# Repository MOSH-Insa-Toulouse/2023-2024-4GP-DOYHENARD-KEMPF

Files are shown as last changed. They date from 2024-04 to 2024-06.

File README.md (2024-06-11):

# **4A GP - Projet "Du capteur au banc de test" - I4PMH21**

## **Sommaire**
+ [Objectif du projet](https://github.com/MOSH-Insa-Toulouse/2023-2024-4GP-DOYHENARD-KEMPF?tab=readme-ov-file#objectif-du-projet)
+ [Livrables](https://github.com/MOSH-Insa-Toulouse/2023-2024-4GP-DOYHENARD-KEMPF?tab=readme-ov-file#livrables)
+ [LTSpice](https://github.com/MOSH-Insa-Toulouse/2023-2024-4GP-DOYHENARD-KEMPF?tab=readme-ov-file#ltspice)
+ [KiCad](https://github.com/MOSH-Insa-Toulouse/2023-2024-4GP-DOYHENARD-KEMPF?tab=readme-ov-file#kicad)
+ [Shield](https://github.com/MOSH-Insa-Toulouse/2023-2024-4GP-DOYHENARD-KEMPF?tab=readme-ov-file#conception-du-shield)
+ [Code Arduino](https://github.com/MOSH-Insa-Toulouse/2023-2024-4GP-DOYHENARD-KEMPF?tab=readme-ov-file#code-arduino)
+ [Application Android](https://github.com/MOSH-Insa-Toulouse/2023-2024-4GP-DOYHENARD-KEMPF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)
+ [Datasheet](https://github.com/MOSH-Insa-Toulouse/2023-2024-4GP-DOYHENARD-KEMPF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)

## **Objectif du projet**
Dans le cadre d'un cours dispensé lors du 2<sup>nd</sup> semestre de 4<sup>ème</sup> année de Génie Physique à l'INSA de Toulouse, il nous a été proposé de réaliser un capteur low-tech à base de graphite, puis d'en faire une analyse critique argumentée pour en cerner les potentialités mais également pour évoquer des solutions d’amélioration. Ainsi, ce projet nous a permis de balayer l’ensemble du domaine : du capteur jusqu’à la réalisation d’une datasheet et du banc de test.

## **Livrables**
* Un shield PCB branché à une board Arduino UNO sur lequel nous retrouverons différents composants tels que :
  - Un capteur graphite
  - Un circuit d'amplification transimpédence
  - Un module Bluetooth
  - Un encodeur rotatoire
  - Un potentiomètre digital (_qui vient remplacer la résistance R2 du circuit d'amplifiaction_)
  - Un capteur de contrainte commercial

* Une simulation LTSpice du circuit transimpédence

* Un fichier KiCad du shield avec l'ensemble des composants cités en amont

* Un code Arduino qui gère le fonctionnement et les communications des 2 à 6 avec la board

* Un fichier APK Android (_conçue à l'aide du site MIT APP Inventor_) qui permet, à partir d'un smartphone Android, de gèrer l'interface avec le shield Arduino UNO par le biais d'une communication Bluetooth

* La datasheet du capteur graphite

## **LTSpice**
Nous avons réalisé une étude de notre circuit à l'aide du logiciel _LTSpice_. En effet, le capteur étudié ayant une résistance de l'ordre du GOhm, le courant délivré est alors trop faible (de l'ordre du nA). Pour qu'il puisse être exploitable, ce signal en courant doit donc être **filtré** de tout bruit parasite puis **amplifié**. C'est précisément le rôle du montage suivant :

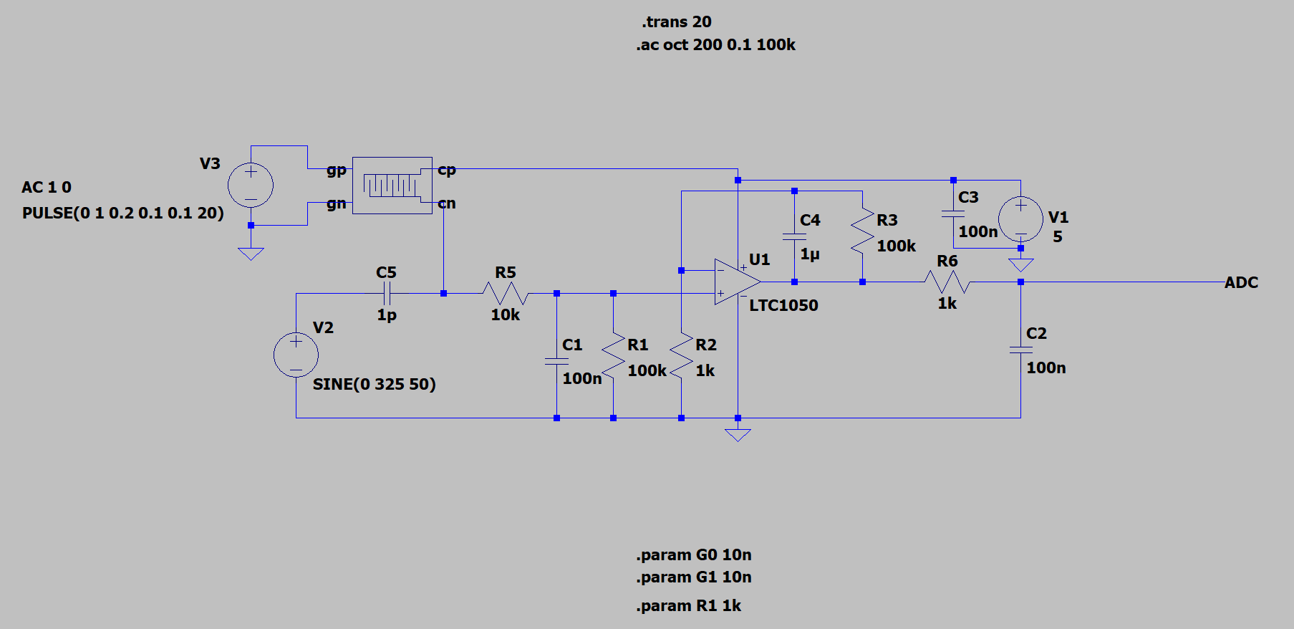
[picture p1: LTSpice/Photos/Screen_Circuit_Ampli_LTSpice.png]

_Circuit d'amplification/atténuation_
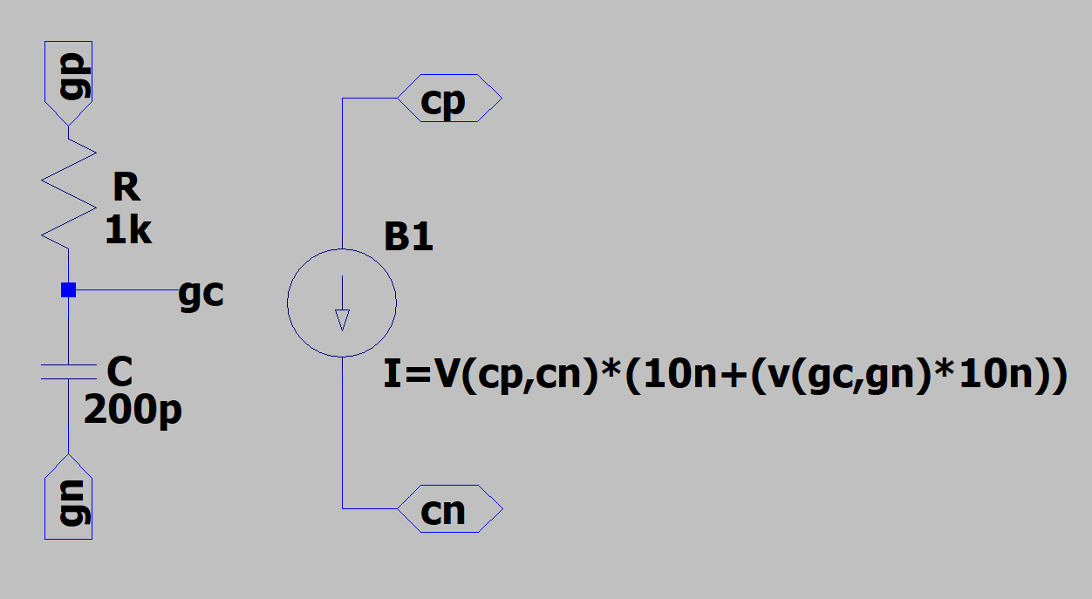
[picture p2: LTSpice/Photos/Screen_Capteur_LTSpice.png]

_Modélisation du capteur_

Ce montage se compose de 3 filtres passe-bas distincts :
- Un 1<sup>er</sup> formé par R<sub>5</sub>, C<sub>1</sub> et R<sub>1</sub>, filtrant les bruits en courant sur le signal d'entrée causés par l’alimentation 5V symbolisé par le 'SINE' + C<sub>3</sub>
- Un 2<sup>nd</sup> formé par C<sub>4</sub> et R<sub>3</sub>, pour réduire la composante de bruit à 50 Hz induite par réseau électrique ambiant
- Un 3<sup>ème</sup> formé par R<sub>6</sub> et C<sub>2</sub>, placé à la sortie de l'amplificateur qui atténue le bruit intrinsèque du circuit

Grâce à ce montage, nous sommes capable de mesurer la résistance du capteur graphite en suivant la formule suivante : $`R_{Meas} = \frac{V_{CC}}{V_{ADC}}*R_1*(1+\frac{R_3}{R_{potentio}})-R_1-R_5`$

Afin de nous assurer que notre circuit jouait bien le rôle de filtreur/amplificateur, nous avons réalisé 2 simulation : une qui vérifiera la correcte amplification du signal en sortie de circuit, l'autre qui permettra de confirmer la bonne atténuation du signal pour des fréquences non souhaitées :

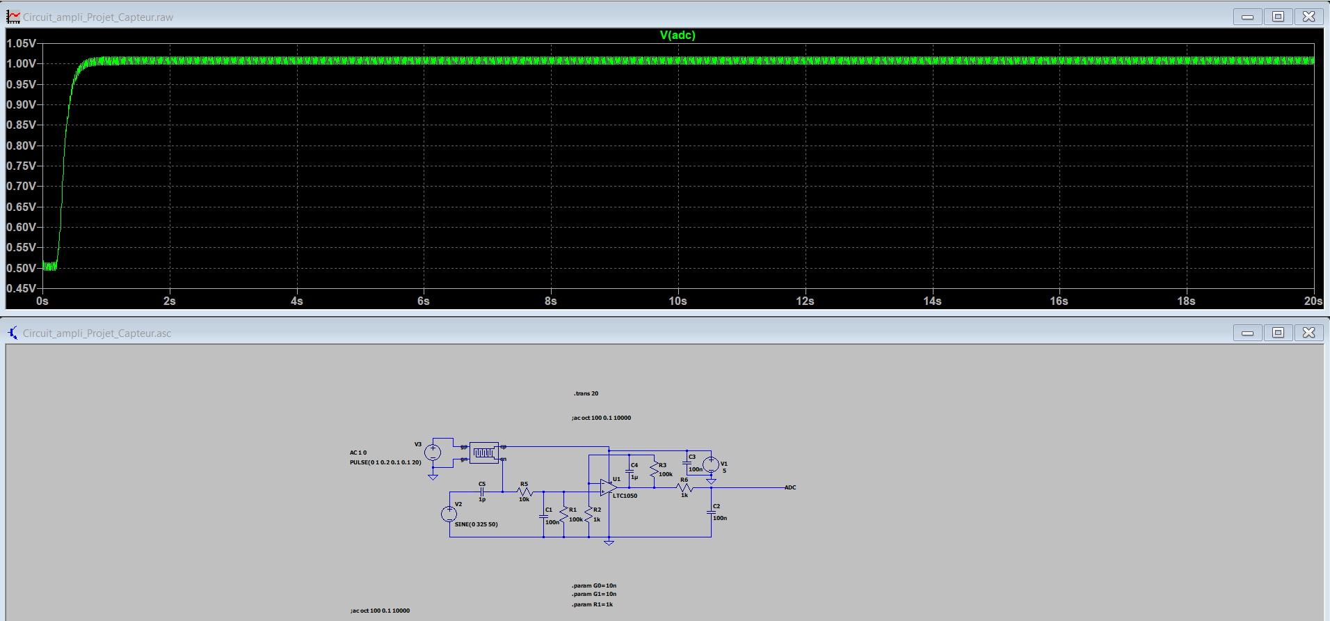
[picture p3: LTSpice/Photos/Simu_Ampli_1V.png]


Nous voyons ici que le signal de sortie est de 1V, soit un ordre de grandeur tout à fait mesurable et donc exploitable dans notre cas.

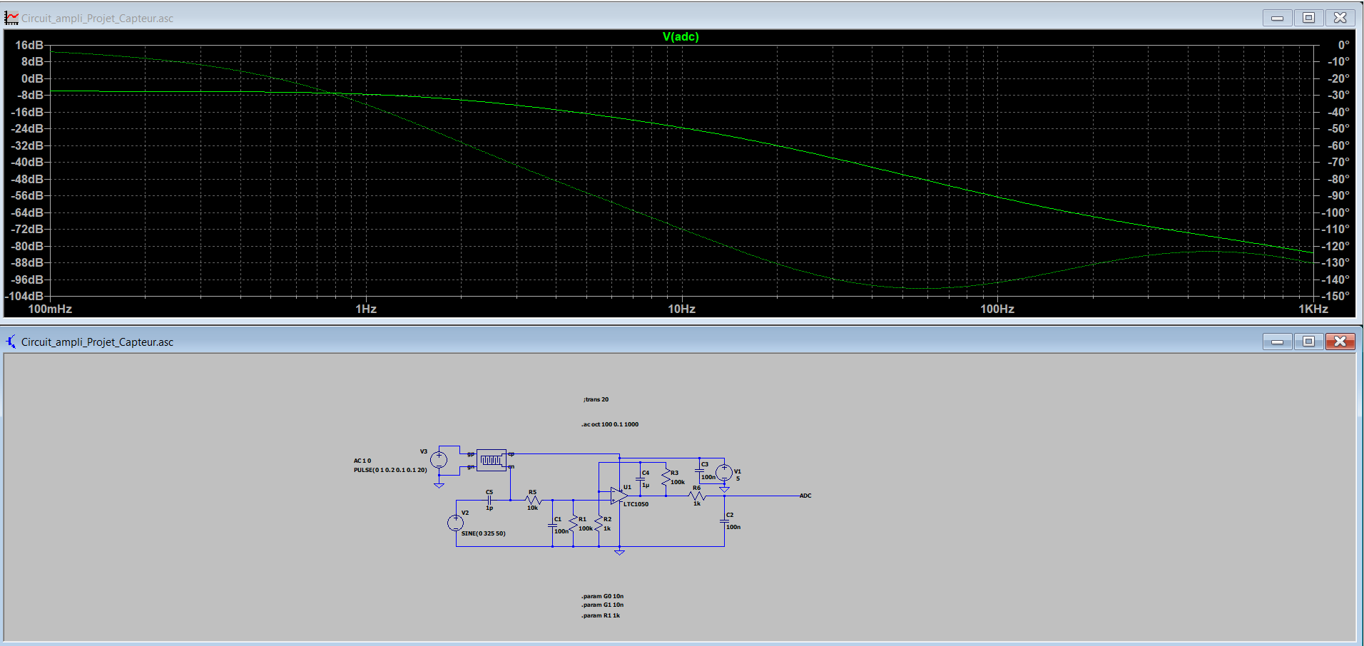
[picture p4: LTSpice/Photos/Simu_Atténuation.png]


Ici, nous avons simulé un courant alternatif grâce auquel il nous sera possible d'observer la réduction du bruit : Nous observons une atténuation d'environ 46 dB à 50 Hz. Le comportement global du circuit est bel est bien passe-bas.

--> La simulation LTSpice est donc conforme aux attentes.

## **KiCad**
Afin de construire un shield PCB qui respecte à la fois les consignes mentionnées dans le document _INSTRUCTIONS for the UF “From the sensor to the test bench” – I4PMH21_ ainsi que les contraintes électroniques, mécaniques et physiques des composants qu'il supportera, il nous a fallu élaborer une maquette virtuelle de ce dernier via le logiciel _KiCad_. Nous avons donc dans un 1<sup>er</sup> temps réalisé une 'schematic' de l'ensemble des composants impliqués :

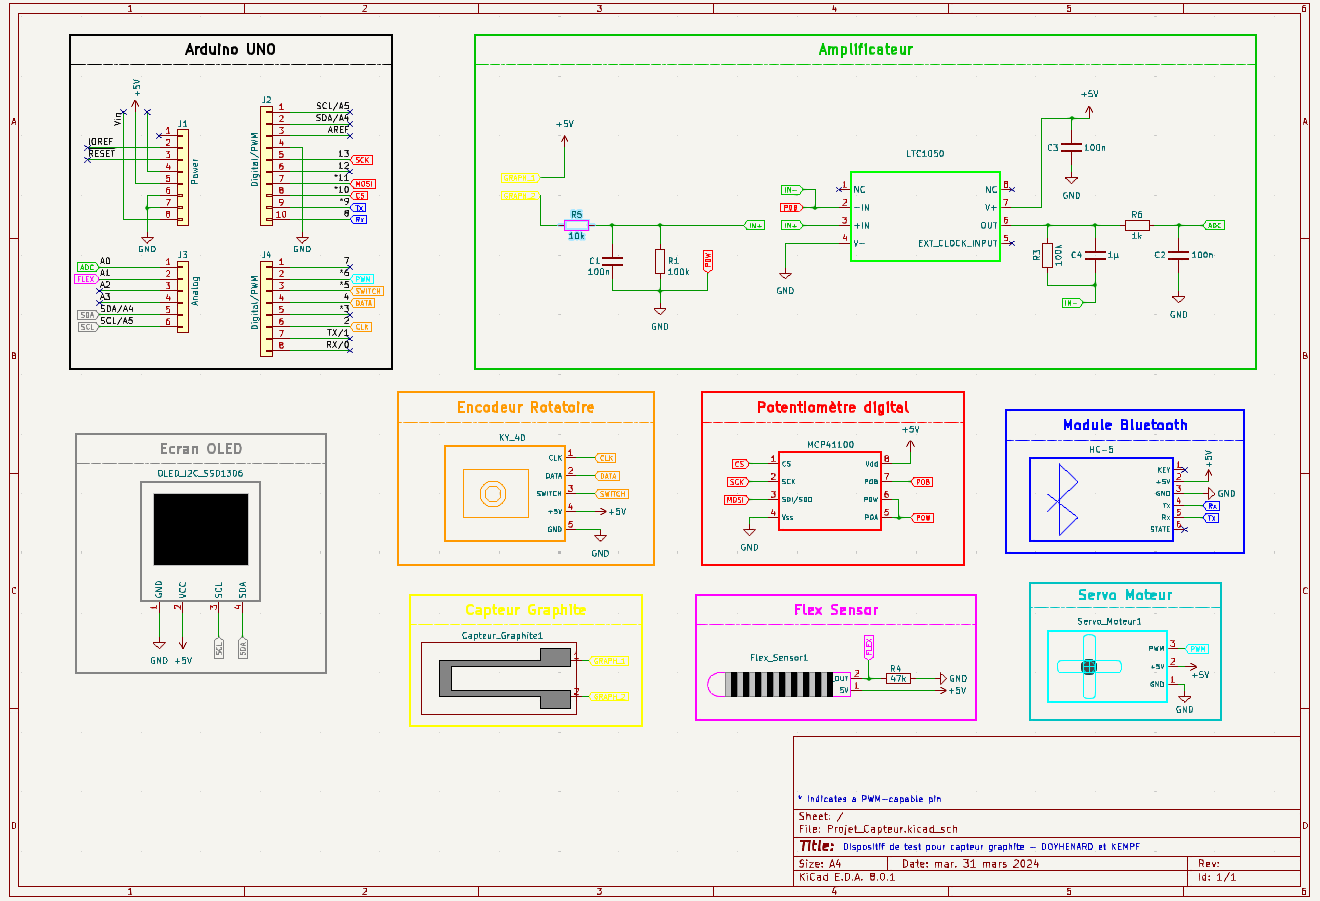
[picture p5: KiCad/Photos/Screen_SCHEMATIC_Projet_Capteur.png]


Nous avons en suite utilisé la partie _PCB_ du logiciel afin de disposer les différents composants sur le shield, en tenant compte de la contrainte liée aux masses, qui doivent être réliées indirectement entre elles via le plan de masse. Nous sommes arrivés au résultat suivant :

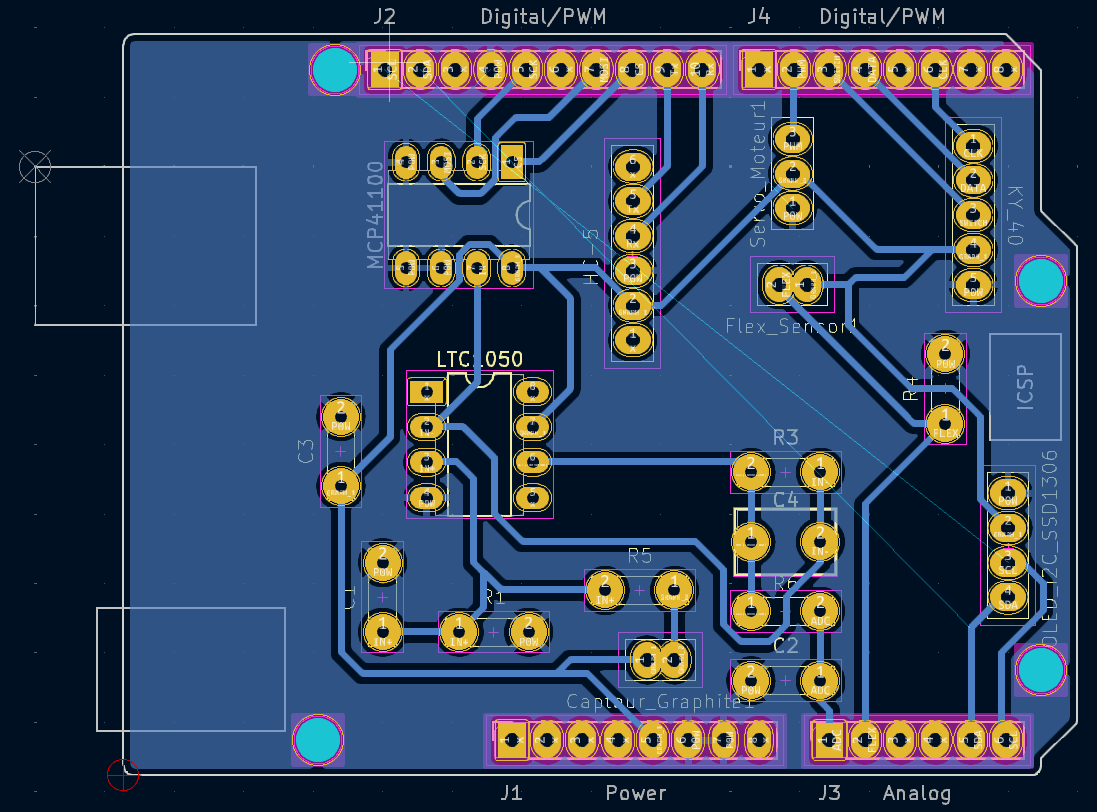
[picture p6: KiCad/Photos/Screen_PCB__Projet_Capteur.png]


Nous avons également effectué un rendu 3D de notre shield afin d'en avoir un 1<sup>er</sup> aperçu 'réaliste', dont voici un cliché pris du dessus :

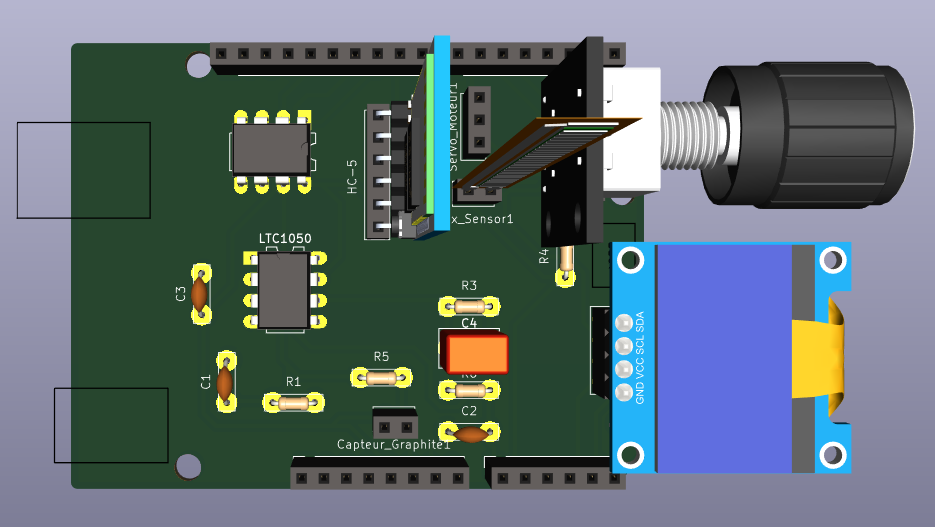
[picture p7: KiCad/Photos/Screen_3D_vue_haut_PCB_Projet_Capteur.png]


## **Conception du shield**
Après validation de notre travail sur _KiCad_ par nos responsables, nous avons procédé à la confection réelle de notre shield, fabriqué à partir d'une plaquette d’époxy recouverte d’une fine couche de cuivre.
Les principales étapes de fabrication sont :
- Une insolation aux UVs de la plaquette grâce au calque modélisé dans la partie PCB de _KiCad_.
- Le retrait de la résine non isolée à l'aide d'un révélateur.
- Le placement de la plaquette dans une solution de percholorure de fer.

A la suite de cela, avons pu assembler les composants sur la plaquette. Pour cela, il a fallu respecter les consignes à appliquer que ce soit au niveau du perçage de la plaquette ou bien du soudage des composants :

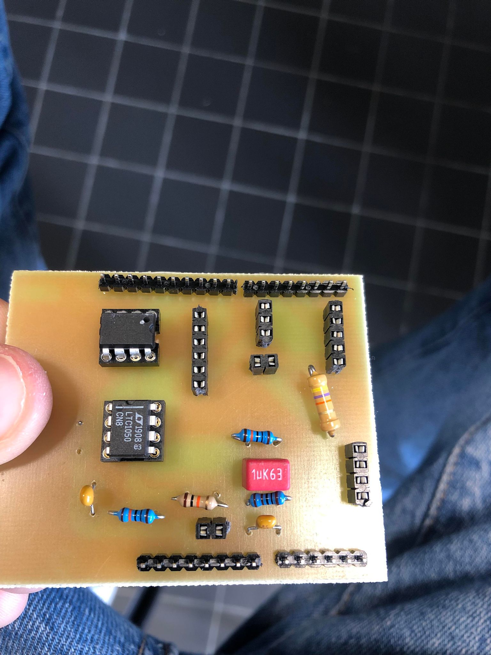
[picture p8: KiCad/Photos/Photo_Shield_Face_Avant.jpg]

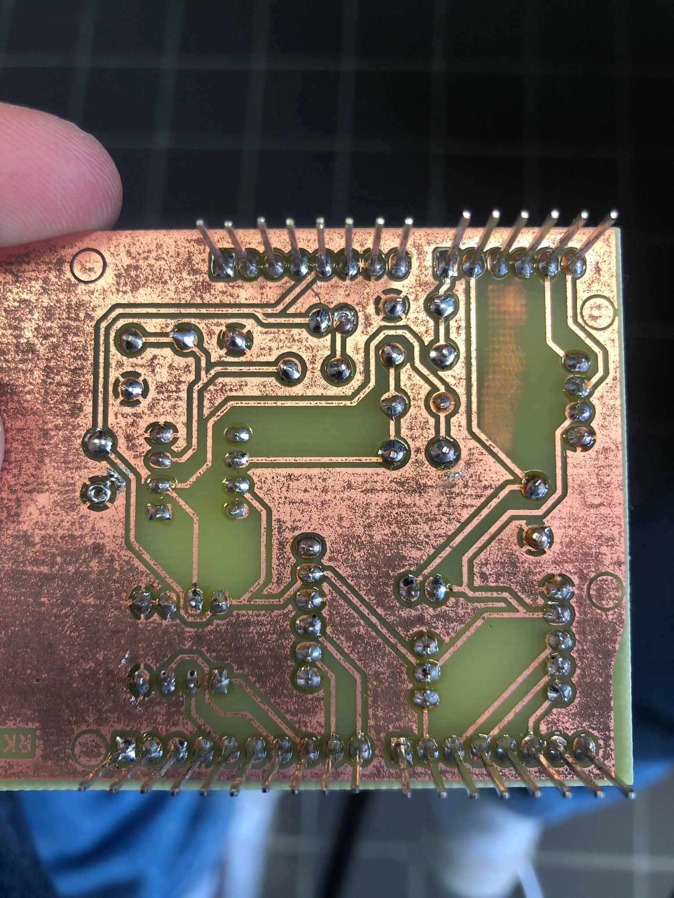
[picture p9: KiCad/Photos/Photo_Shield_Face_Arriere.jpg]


> [!NOTE]
> Nous avons finalement décidé de ne pas nous servir de Servomoteur du fait d'un manque de temps.

## **Code Arduino**
En parallèle de la partie _KiCad_, nous nous sommes attelés à la programmation du **[code Arduino](https://github.com/MOSH-Insa-Toulouse/2023-2024-4GP-DOYHENARD-KEMPF/blob/main/Code%20Arduino/Code_V_Finale.c)** qui permettra la commuication de chacun des composants entre eux mais aussi avec l'Arduino UNO, ainsi qu'avec un smartphone via l'application Android.

## **Application Bluetooth pour Android**
Nous avons réalisé une **[application Android](https://github.com/MOSH-Insa-Toulouse/2023-2024-4GP-DOYHENARD-KEMPF/tree/main/Application%20Android)** à l'aide du site _MIT App Inventor_. Cette application permet de lire les valeurs des capteurs en temps réel, mais aussi de les stocker pour établir des courbes de variation de résistance en fonction de la déformation qui leur est appliquée : 

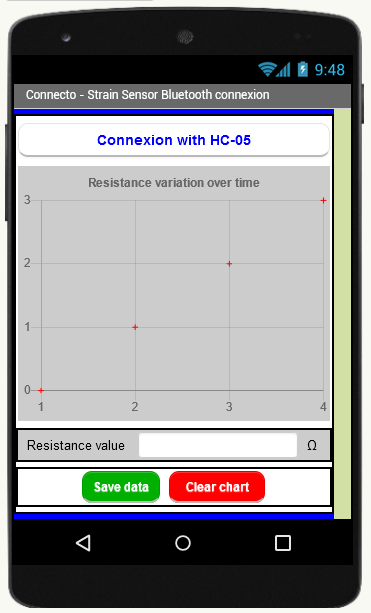
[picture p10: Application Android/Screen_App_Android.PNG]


## **Datasheet du capteur graphite**
La rédaction de la datasheet induit plusieurs tests préalables de nos capteurs. Pour ce faire, nous nous sommes servis d'un banc de test imprimé en 3D, composé de 7 demi-disques allant de 1cm à 5cm de diamètre. Les capteurs quant à eux, ont tous les mêmes dimensions, mais sont usinés avec différents type de crayons à papier, allant du H au B en passant par le F et comprenant nombre de leur dérivées (HB, 2H, 4H, 4B et 6B dans notre cas) :

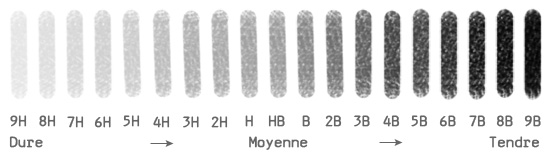
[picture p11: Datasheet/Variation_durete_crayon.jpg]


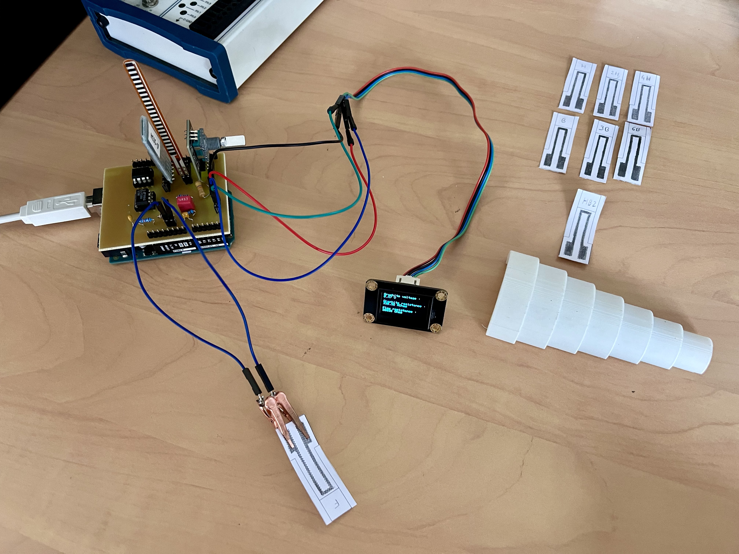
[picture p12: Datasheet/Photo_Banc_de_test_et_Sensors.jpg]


Nous avons ainsi effectué plusieurs mesures pour chaque type de crayon, ainsi que pour le flex sensor commercial avec lequel nous comparerons nos résultats : 
- Mesure de résistance à plat
- Série de mesure de résistance avec une déformation en **extension** en suivant certains demi-disques sélectionnés.
- Série de mesure de résistance avec une déformation en **compression** avec les mêmes demi-disques.

> [!NOTE]
> Des valeurs incohérentes ont été observées pour certains capteurs. Nous avons donc décidé de ne pas les retenir dans nos résultats finaux.

--> Nous avons pu par la suite établir des graphes montrant la variation relative de résistance des différents capteurs en fonction de la déformation subie (compression ou extension, à divers degré d'intensité) que l'on retrouve dans la **[datasheet](https://github.com/MOSH-Insa-Toulouse/2023-2024-4GP-DOYHENARD-KEMPF/blob/main/Datasheet/%5BDataheet%5D%20-%20Pencil-Drawn%20Strain%20Gauge.pdf)** de nos capteurs graphite.

> [!WARNING]
> Les mesures ayant été difficiles, du fait d'une faible reproductibilité induite par des paramètres variants (densité de graphite au cours du temps, faux-contact électrique détecté en fin de prise de mesures), les résultats en valeurs absolues n'ont pas répondu à nos exigeances. Il nous a donc fallu nous appuyer sur l'aide de [collègues INSAïens](https://github.com/MOSH-Insa-Toulouse/2022-2023-Conan-Pistre) de la promo 2024, sans qui les courbes de mesures ne figureraient pas.

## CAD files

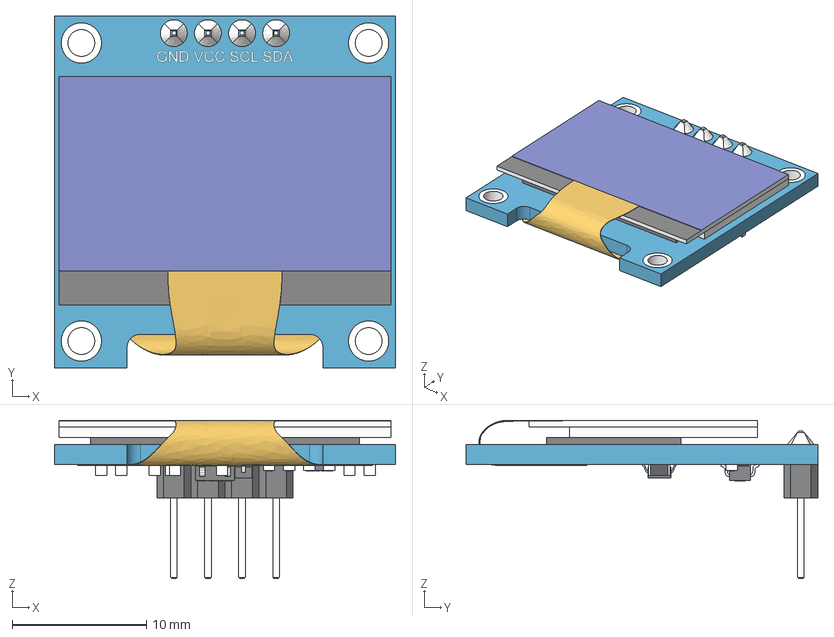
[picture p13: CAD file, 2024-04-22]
KiCad/3DModels/SSD1306_OLED_Display(128x64).step
25.4 x 26.2 x 11.8 mm
board
screen
pin_header
soldering
smd_capacitor
smd_capacitor (1)
914_smd_resistor
472_smd_resistor x 3
t4_smd_diode
smd_capacitor (2)
smd_capacitor (3)
smd_capacitor (4)
smd_capacitor (5)
smd_capacitor (6)
472_smd_resistor (1)
SOT-23_XC6206 v3
smd_capacitor (7)
flat_cable

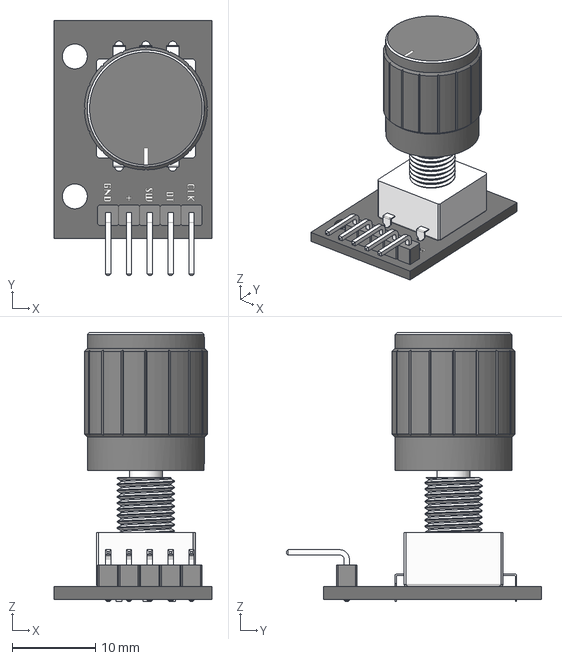
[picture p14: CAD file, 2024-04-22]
KiCad/3DModels/Rotary Encoder - KY-040.step
19.0 x 30.8 x 32.4 mm

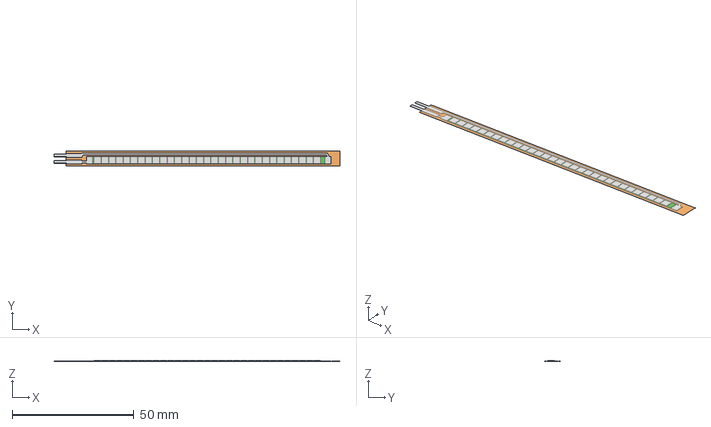
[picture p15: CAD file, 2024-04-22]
KiCad/3DModels/FS-L-095-103-ST.stp
117.2 x 6.35 x 0.347 mm

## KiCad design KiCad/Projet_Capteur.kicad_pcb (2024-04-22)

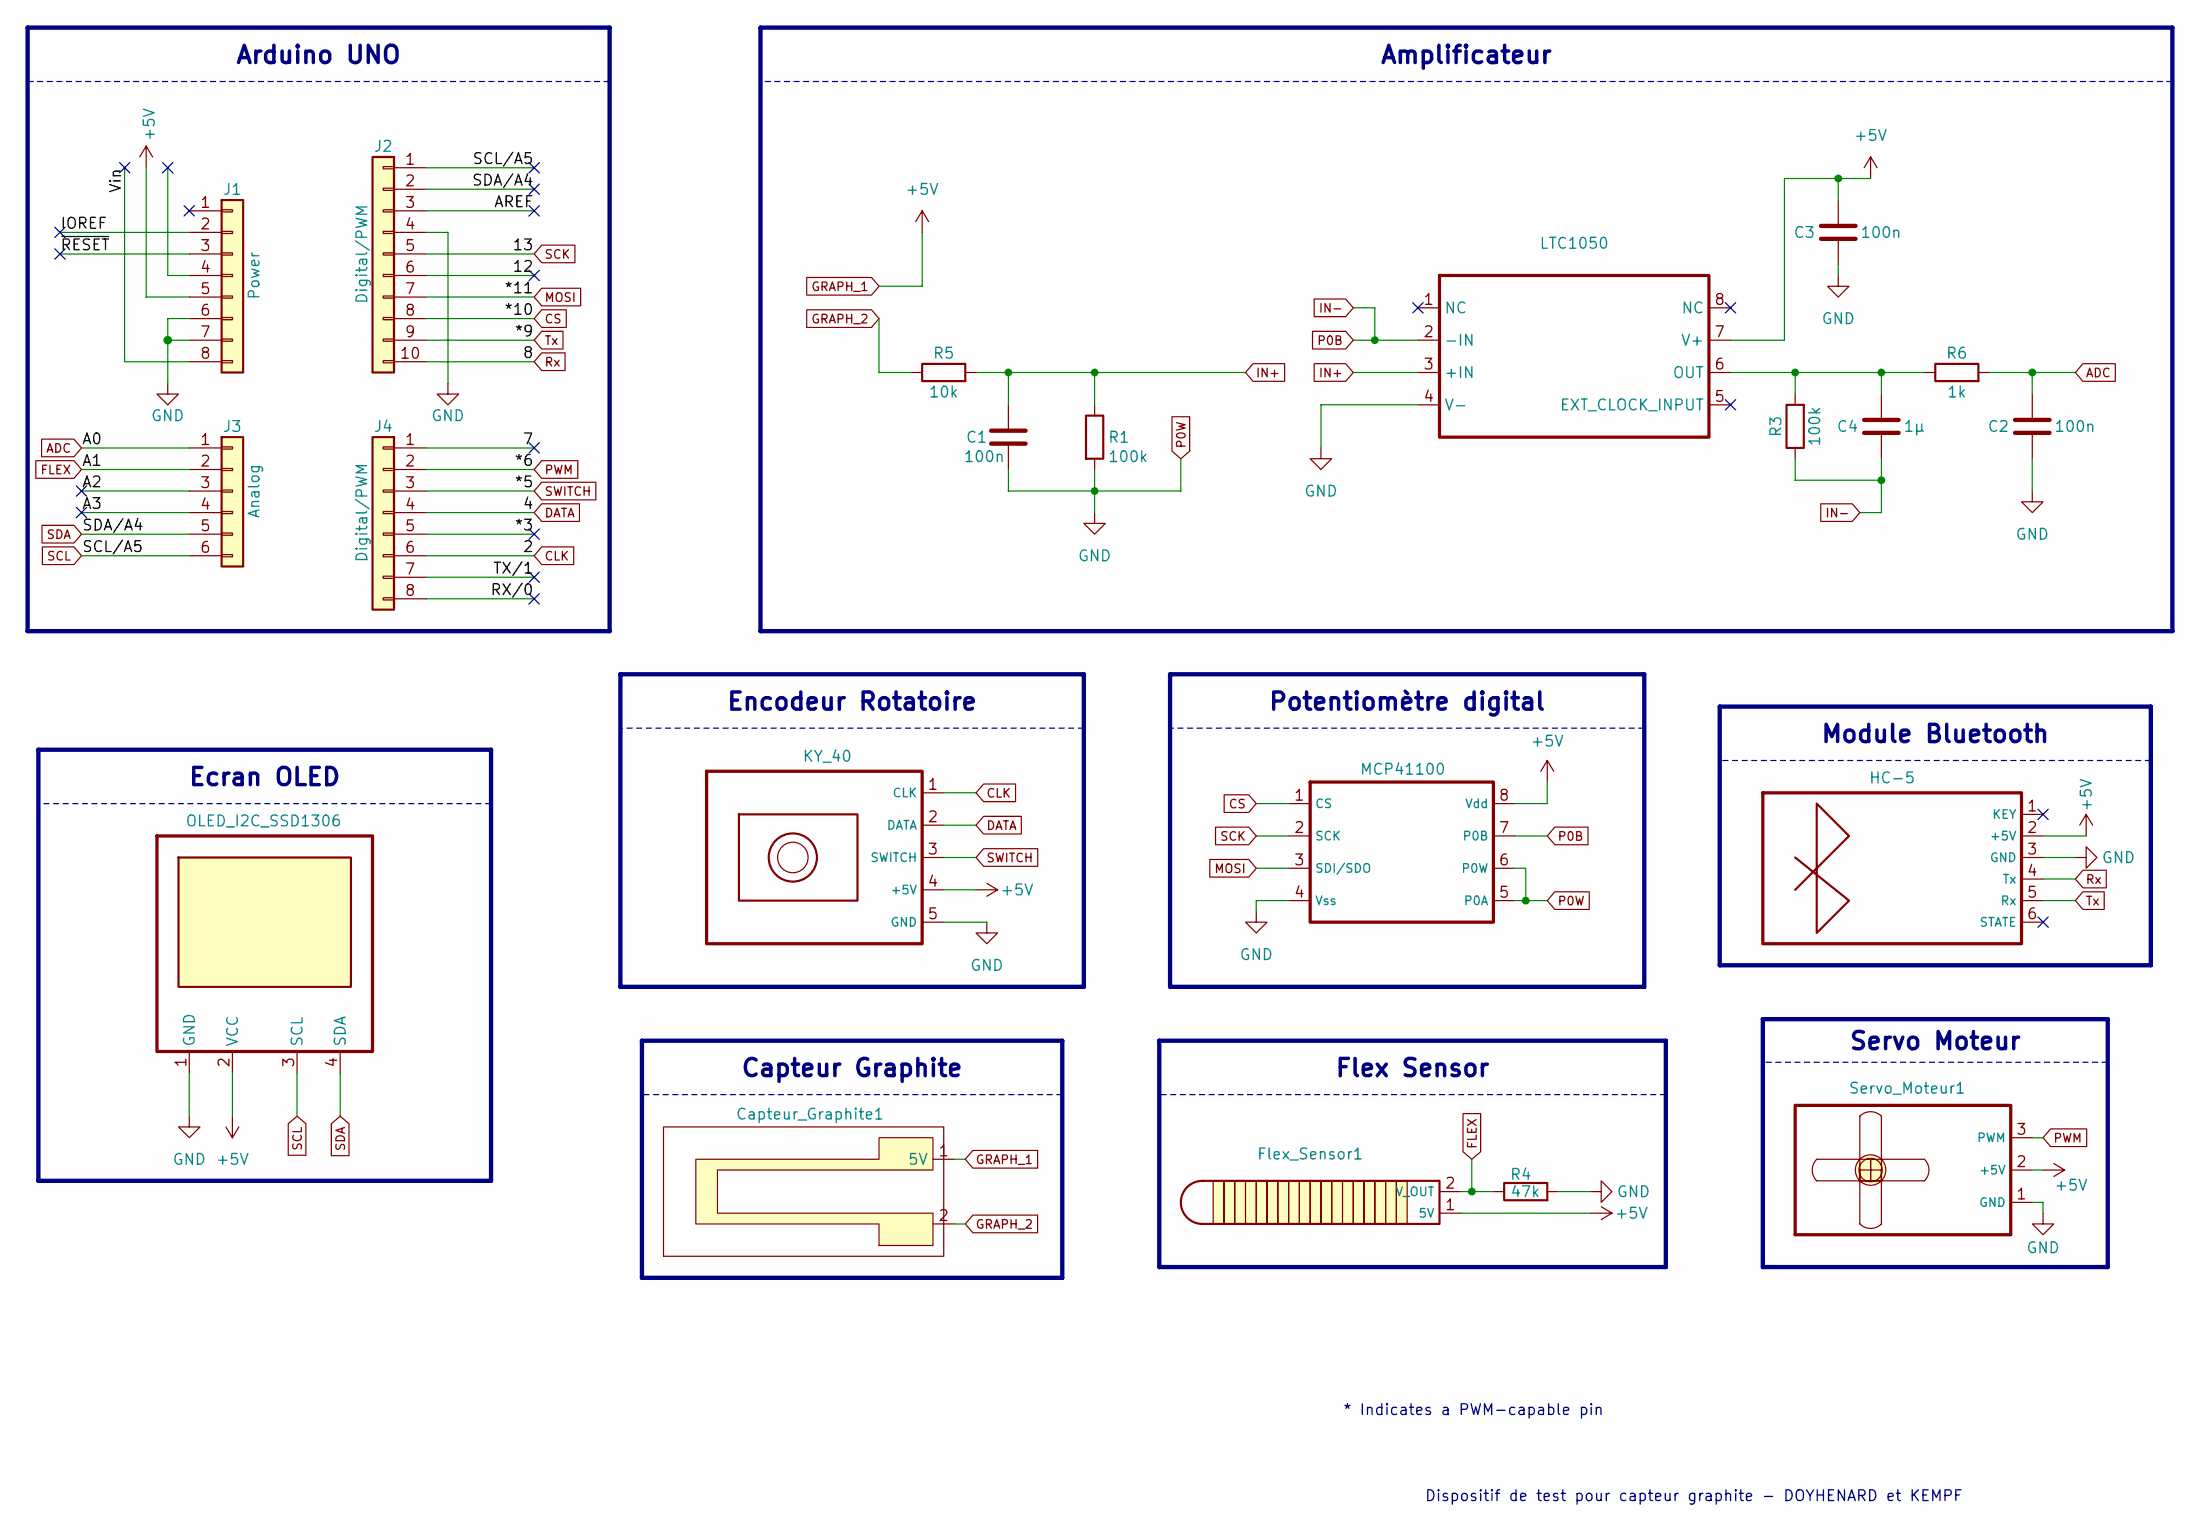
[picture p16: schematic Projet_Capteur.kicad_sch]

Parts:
C1, C2, C3: 100n; R_ou_C_a_100n
C4: 1µ; C_Rect_L7.0mm_W4.5mm_P5.00mm
Capteur_Graphite1: Sensor
Flex_Sensor1: Sensor
HC-5: HC-05 (Bluetooth)
J1: Power; PinSocket_1x08_P2.54mm_Vertical
J2: Digital/PWM; PinSocket_1x10_P2.54mm_Vertical
J3: Analog; PinSocket_1x06_P2.54mm_Vertical
J4: Digital/PWM; PinSocket_1x08_P2.54mm_Vertical
KY_40: Encodeur KY_040
LTC1050: DIP-8_W7.62mm_LongPads
MCP41100: DIP-8_W7.62mm_LongPads
OLED_I2C_SSD1306: OLED SSD1306
R1, R3: 100k; R_ou_C_a_100n
R4: 47k; R_ou_C_a_100n
R5: 10k; R_ou_C_a_100n
R6: 1k; R_ou_C_a_100n
Servo_Moteur1: Servo Moteur

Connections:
/7: J4.1
/12: J2.6
/*3: J4.5
/A2: J3.3
/A3: J3.4
/AREF: J2.3
/IOREF: J1.2
/RX/0: J4.8
/TX/1: J4.7
/Vin: J1.8
/~RESET: J1.3
ADC: C2.1, J3.1, R6.2
CLK: J4.6, KY_40.1 (CLK)
CS: J2.8, MCP41100.1 (CS)
DATA: J4.4, KY_40.2 (DATA)
FLEX: Flex_Sensor1.2 (V_OUT), J3.2, R4.1
GRAPH_1: C3.1, Capteur_Graphite1.1 (5V), Flex_Sensor1.1 (5V), HC-5.2 (+5V), J1.5, KY_40.4 (+5V), LTC1050.7 (V+), MCP41100.8 (Vdd), OLED_I2C_SSD1306.2 (VCC), Servo_Moteur1.2 (+5V)
GRAPH_2: Capteur_Graphite1.2, R5.1
IN+: C1.1, LTC1050.3 (+IN), R1.1, R5.2
IN-: C4.2, LTC1050.2 (-IN), MCP41100.7 (P0B), R3.1
MOSI: J2.7, MCP41100.3 (SDI/SDO)
unnamed: C4.1, LTC1050.6 (OUT), R3.2, R6.1
P0W: C1.2, C2.2, C3.2, HC-5.3 (GND), J1.6, J1.7, J2.4, KY_40.5 (GND), LTC1050.4 (V-), MCP41100.4 (Vss), MCP41100.5 (P0A), MCP41100.6 (P0W), OLED_I2C_SSD1306.1 (GND), R1.2, R4.2, Servo_Moteur1.1 (GND)
PWM: J4.2, Servo_Moteur1.3 (PWM)
Rx: HC-5.4 (Tx), J2.10
SCK: J2.5, MCP41100.2 (SCK)
SCL: J2.1, J3.6, OLED_I2C_SSD1306.3 (SCL)
SDA: J2.2, J3.5, OLED_I2C_SSD1306.4 (SDA)
SWITCH: J4.3, KY_40.3 (SWITCH)
Tx: HC-5.5 (Rx), J2.9

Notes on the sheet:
Module Bluetooth
Flex Sensor
Potentiomètre digital
Servo Moteur
Encodeur Rotatoire
Arduino UNO
Capteur Graphite
Amplificateur
Ecran OLED
* Indicates a PWM-capable pin
Dispositif de test pour capteur graphite - DOYHENARD et KEMPF

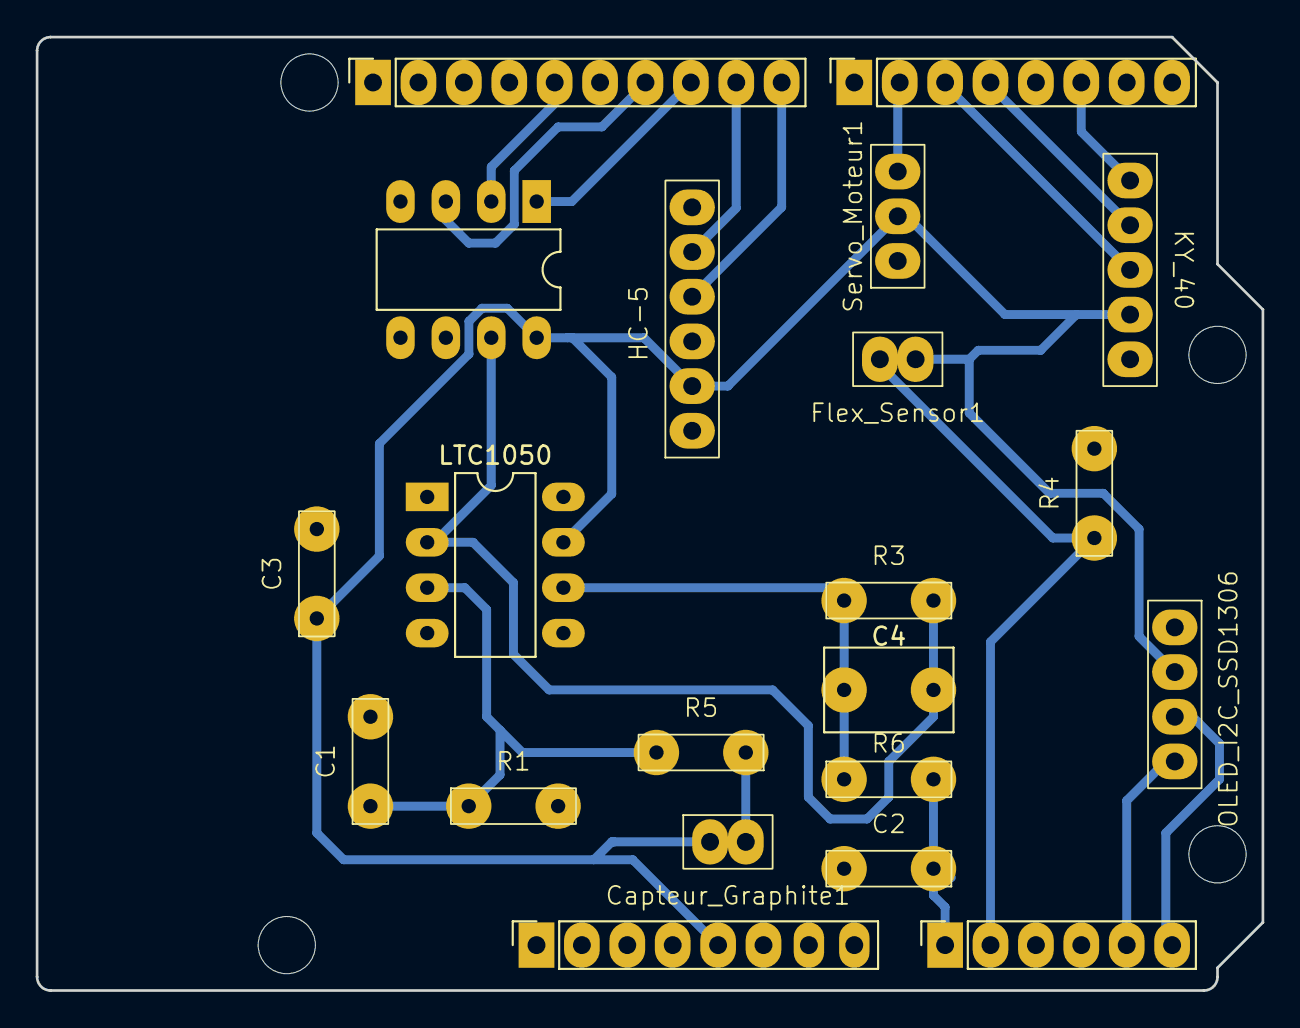
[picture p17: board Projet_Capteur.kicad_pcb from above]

Board: 2 copper layers, 68.6 x 53.3 mm, 25 parts (0 on the bottom side), 19 nets.

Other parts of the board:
MH1, MH2, MH3, MH4: MountingHole_3.2mm

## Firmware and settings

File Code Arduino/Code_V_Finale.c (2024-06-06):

//////////////////////////////////////////// LIBRAIRIES UTILISEES ////////////////////////////////////////////



#include <Wire.h>
#include <Adafruit_GFX.h>
#include <Adafruit_SSD1306.h>
#include <SPI.h>
#include <SoftwareSerial.h>


//////////////////////////////////////////// DECLARATIONS ET DEFINITIONS DIVERSES ////////////////////////////////////////////



// Définition des pins analogiques pour les capteurs
#define PIN_GRAPH_SENSOR A0 // Capteur graphite sur l'entrée analogique A0
#define PIN_FLEX_SENSOR A1 // Flex sensor sur l'entrée A1

// Définition des pins numériques pour l'encodeur rotatif
#define CLK  2  
#define DT  4  
#define SW  5 

// Définition des broches RXD et TXD du module Bluetooth HC-05
#define BT_TX 9 // Broche TXD du module Bluetooth connectée à la broche 9 d'Arduino
#define BT_RX 8 // Broche RXD du module Bluetooth connectée à la broche 8 d'Arduino

// Déclaration d'un objet de type SoftwareSerial pour la communication avec le module Bluetooth
SoftwareSerial bluetooth(BT_TX, BT_RX);

// Déclaration de l'écran OLED avec la bibliothèque AdaFruit
#define SCREEN_WIDTH 128    // Taille horizontale de l'écran OLED  
#define SCREEN_HEIGHT 64    // Taille verticale 
#define OLED_RESET    -1    // Reset de l'écran est le même que celui de l'Arduino Uno
#define SCREEN_ADDRESS 0x3C // Adresse I2C de l'écran

Adafruit_SSD1306 display(SCREEN_WIDTH, SCREEN_HEIGHT, &Wire, OLED_RESET);

// Déclaration liées aux menus de l'écran OLED
int selectedItem = 0;
bool inSubMenu = false;
const int numItems = 2;
const char *menuItems[] = {"1. Sensors values", "2. R2 variation"};

// Déclaration pour le potentiomètre digital
const byte csPin           = 10;      
const int  maxPositions    = 256;     
const long rAB             = 50000.0;    
const byte rWiper          = 125;     
const byte pot0            = 0x11;    // pot0 addr
const byte pot0Shutdown    = 0x21;    // pot0 shutdown
int pos_res_variable = 5; // Fixe la résistance initiale du potentiomètre digital

// Déclaration pour le flex sensor et le capteur graphite
const float VCC = 5.0;
const float flexR_DIV = 39000.0;
const float flexflatResistance = 25000.0;
const float flexbendResistance = 100000.0;
float tension_graphite = 0;
float tension_flex = 0;
long resistance_variable = 0;
float resistance_graphite = 0;
long resistance_flex = 0;
char resultGraphite[15];
char buffer[15];
char resultFlex[15];
char buffer_flex[15];

// Déclaration pour l'encodeur rotatif
volatile unsigned int lastStateSW; // variable qui enregistre l'état du bouton à la boucle précédente



//////////////////////////////////////////// SETUP ////////////////////////////////////////////



void setup() {
  Serial.begin(9600);
  bluetooth.begin(9600);
  
  // Initialisation des pins 
  pinMode(CLK, INPUT_PULLUP);
  pinMode(DT, INPUT_PULLUP);
  pinMode(SW, INPUT_PULLUP);
  pinMode(PIN_GRAPH_SENSOR, INPUT);
  pinMode(PIN_FLEX_SENSOR, INPUT);
    
  lastStateSW = digitalRead(SW); // Vérifie l'état du bouton au lancement du programme

  attachInterrupt(digitalPinToInterrupt(CLK), doEncoder, CHANGE); // Définir les interruptions sur l'encodeur rotatif
 
  // Initialisation de l'écran OLED
  if(!display.begin(SSD1306_SWITCHCAPVCC, SCREEN_ADDRESS)) {
    Serial.println(F("Echec de l'allocation SSD1306"));
    for(;;);
  }
  display.clearDisplay();

  // Afficher le texte personnalisé au démarrage
  display.setTextSize(2);
  display.setTextColor(SSD1306_WHITE);
  display.setCursor(39, 10); // Ajuster les coordonnées pour centrer le texte
  display.println("INSA");
  display.setCursor(63, 31);
  display.setTextSize(1);
  display.println("-");
  display.setCursor(27, 42);
  display.println("Strain sensor");
  display.display();
  delay(2000);  // Attendre 2 secondes avant d'effacer l'écran

  display.clearDisplay();  // Effacer l'écran après le démarrage

  // Initialisation de la communication avec le potentiomètre digital
  digitalWrite(csPin, HIGH);        
  pinMode(csPin, OUTPUT);           
  SPI.begin();
}



//////////////////////////////////////////// LOOP ////////////////////////////////////////////



void loop() {
  // Lecture de l'état du bouton poussoir de l'encodeur pour la navigation dans les sous-menus
  int stateSW = digitalRead(SW);
  if (stateSW != lastStateSW && stateSW == LOW) {
    inSubMenu = !inSubMenu;
  }
  lastStateSW = stateSW;

  setPotWiper(pot0, pos_res_variable); // Modifie la résistance du potentiomètre

  // Mesures des capteurs et de la résistance variable
  tension_graphite = analogRead(PIN_GRAPH_SENSOR) * VCC / 1023.0;
  resistance_variable = ((rAB * pos_res_variable) / maxPositions) + rWiper;
  resistance_graphite = ((1 + (100000.0 / resistance_variable)) * 100000.0 * (VCC / tension_graphite) - 110000.0) / 1000000.0;
  
  tension_flex = analogRead(PIN_FLEX_SENSOR) * VCC / 1023.0;
  resistance_flex = flexR_DIV * (VCC / tension_flex - 1);

  // Gestion des différents menus sur l'écran OLED
  display.clearDisplay();

  if (!inSubMenu) {
    display.clearDisplay();
    display.setTextSize(2);
    display.setTextColor(SSD1306_WHITE);
    display.setCursor(0, 0);
    display.println(" MAIN MENU");
    display.setTextSize(1);
    display.print("---------------------");
    display.setCursor(0, 35);
    for (int i = 0; i < numItems; ++i) {
      if (i == selectedItem) {
        display.print("> ");
      } else {
        display.print("  ");
      }
      display.println(menuItems[i]);
    }

  } else {
    display.setTextColor(SSD1306_WHITE);
    display.setCursor(0, 0);

    switch (selectedItem) {
      case 0:
        display.println(F("Graphite voltage :  "));
        display.print(tension_graphite);
        display.println(F(" V"));
        display.println();
        display.println(F("Graphite resistance :"));
        display.print(resistance_graphite);
        display.println(F(" MOhms"));
        display.println();
        display.println(F("Flex resistance : "));
        display.print(resistance_flex);
        display.println(F(" Ohms"));
        break;

      case 1:             
        display.println();
        display.println();
        display.println(F("R2 variation :"));
        display.print(resistance_variable);
        display.println(F(" Ohms"));
        display.println();
        display.println(F("Graphite voltage :  "));
        display.print(tension_graphite);
        display.println(F(" V"));
        break;

      default:
        display.println(F("Option inconnue"));
        break;
    }
  }

  display.display();

  // Bluetooth
  dtostrf(tension_graphite, 4, 2, buffer); // Transforme la mesure float en une chaîne de caractères    
  sprintf(resultGraphite, "g%s\n", buffer); // Remplit le tableau resultGraphite de la mesure au format g"mesure"\n pour rendre compatible les données avec l'application
  bluetooth.write(resultGraphite); // Envoie le contenu du tableau vers le module Bluetooth
  delay(100);    
  
  dtostrf(tension_flex, 4, 2, buffer_flex);
  sprintf(resultFlex, "f%s\n", buffer_flex);
  bluetooth.write(resultFlex);

  if (bluetooth.available()) {
    // Lit les données reçues depuis le module Bluetooth
    char receivedChar = bluetooth.read();
    // Affiche les données reçues sur le moniteur série
    Serial.print(receivedChar);
  }

  delay(100);
}



//////////////////////////////////////////// FONCTIONS UTILISEES ////////////////////////////////////////////



// Fonction lors de l'interrupt de l'encodeur rotatif
void doEncoder() {
  // Cas du menu principal
  if (!inSubMenu) { 
    if (digitalRead(DT) == HIGH) {
      selectedItem = (selectedItem == 0) ? numItems - 1 : selectedItem - 1; // [Sens horaire] -> du haut vers le bas, revient en haut une fois la fin de la liste atteinte
    } else {
      selectedItem = (selectedItem == numItems - 1) ? 0 : selectedItem + 1; // [Sens anti-horaire] -> du bas vers le haut
    }
  } 
  // Cas du sous-menu de choix du gain
  else {
    if (selectedItem == 1) {
      if (digitalRead(DT) == HIGH) {      
        pos_res_variable++;
        if (pos_res_variable >= 255) {
          pos_res_variable = 255;
        }
      } else {
        pos_res_variable--;
        if (pos_res_variable <= 1) {
          pos_res_variable = 1;
        }
      }
    }
  }
}

// Fonction pour régler la valeur du potentiomètre
void setPotWiper(byte address, int value) {
  digitalWrite(csPin, LOW);
  SPI.transfer(address);
  SPI.transfer(value);
  digitalWrite(csPin, HIGH);
}

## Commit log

2024-04-13 Update README.md
    Début de rédaction
2024-04-13 Create Partie PCB
